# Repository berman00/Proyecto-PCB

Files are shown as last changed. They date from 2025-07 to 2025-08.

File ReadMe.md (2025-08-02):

*english version below*

# Proyecto de Diseño Avanzado de circuitos impresos

por Valentin Berman

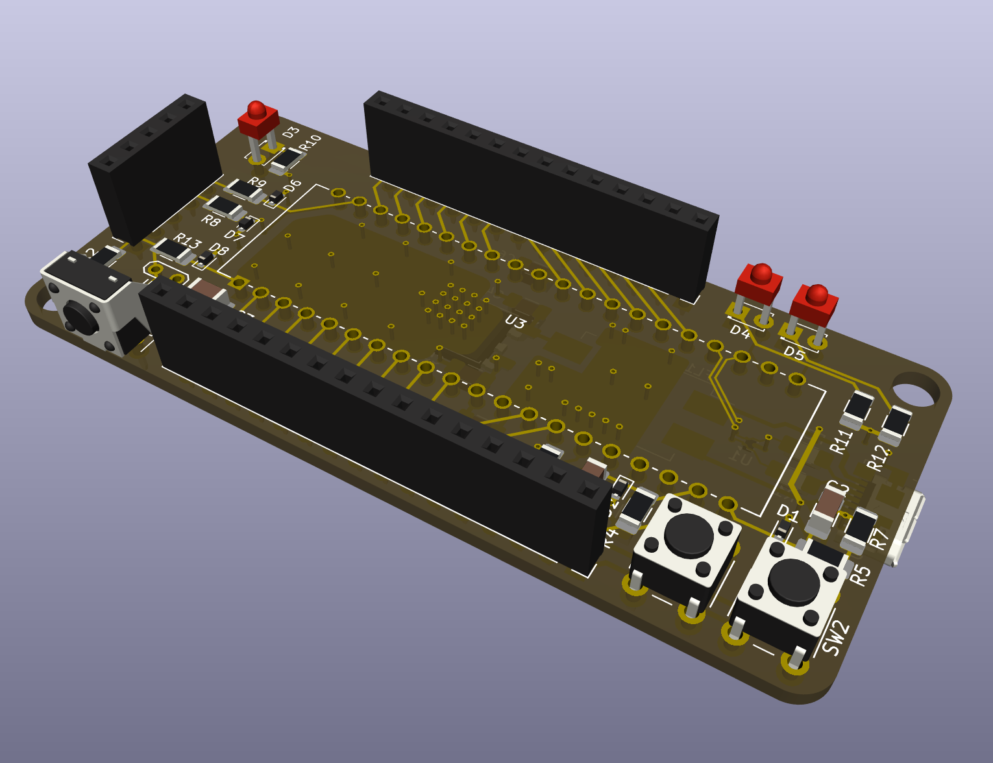
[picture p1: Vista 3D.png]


## Descripción

PCB para un microcontrolador [PIC18 45K50 de Microchip](https://www.microchip.com/en-us/product/PIC18F45K50) con una interfaz humano-máquina simple, pines de GPIO y conector USB.

Diseñado con [KiCad](https://www.kicad.org/).

## Objetivos de diseño

- Usar **partición vertical** para aumentar la compatibilidad electromagnética interna y hacer una placa más compacta. En otras palabras separar los componentes ruidosos de los componentes susceptibles colocándolos en caras opuestas del PCB.

- Elegir componentes que se puedan **soldar a mano** en la medida de lo posible.

- Diseñar **protección contra ESD** en lugares susceptibles.

- Tomar precauciones para **reducir el ruido de alimentación**.

## Guía para usar

Si tenés git instalado podes clonar el repositorio con el comando:

```shell
git clone https://github.com/berman00/Proyecto-PCB.git
```

Sino, podes descargar todos los archivos como un .zip haciendo click en el botón "Code" y luego "Descargar zip".

La repo esta organizada de la siguiente manera:

- **Datasheets:** hojas de datos referenciadas en el proyecto.

- **Entregables:** archivos entregados para evaluar el proyecto.

- **Esquemáticos de referencia:** Esquemáticos de proyectos similares.

- **Proyecto-diseño-PCB:** Proyecto de KiCad.

- **ul_PIC18LF45K50-I-P:** Modelo del micro PIC18 descargado de Microchip.

Si solo querés descargar el esquemático, o el proyecto de KiCad, los podes encontrar en los [releases](https://github.com/berman00/Proyecto-PCB/releases).

# Advanced PCB Design Project

by Valentin Berman



## Description

PCB for a [PIC18 45K50 Microcontroller by Microchip](https://www.microchip.com/en-us/product/PIC18F45K50) with a simple human-machine interface, GPIO pins, and USB connector.

Designed with [KiCad](https://www.kicad.org/).

## Design Goals

- Use **vertical partitioning** to improve internal electromagnetic compatibility and make a more compact board. In other words, separate noisy components from sensitive ones by placing them on opposite sides of the PCB.

- Choose components that can be **hand soldered** as much as possible.

- Design **ESD protection** in susceptible areas.

- Take precautions to **reduce power supply noise**.

## Usage Guide

If you have Git installed, you can clone the repository with the command:

```shell
git clone https://github.com/berman00/Proyecto-PCB.git
```

Otherwise, you can download all the files as a .zip by clicking the "Code" button and then "Download zip".

The repo is organized as follows:

- Datasheets: Data sheets referenced in the project.

- Entregables: Files submitted for project evaluation.

- Esquemáticos de referencia: Schematics from similar projects.

- Proyecto-diseño-PCB: KiCad project.

- ul_PIC18LF45K50-I-P: PIC18 microcontroller model downloaded from Microchip.

If you just want to download the schematic or the KiCad project, you can find them in the [releases](https://github.com/berman00/Proyecto-PCB/releases).

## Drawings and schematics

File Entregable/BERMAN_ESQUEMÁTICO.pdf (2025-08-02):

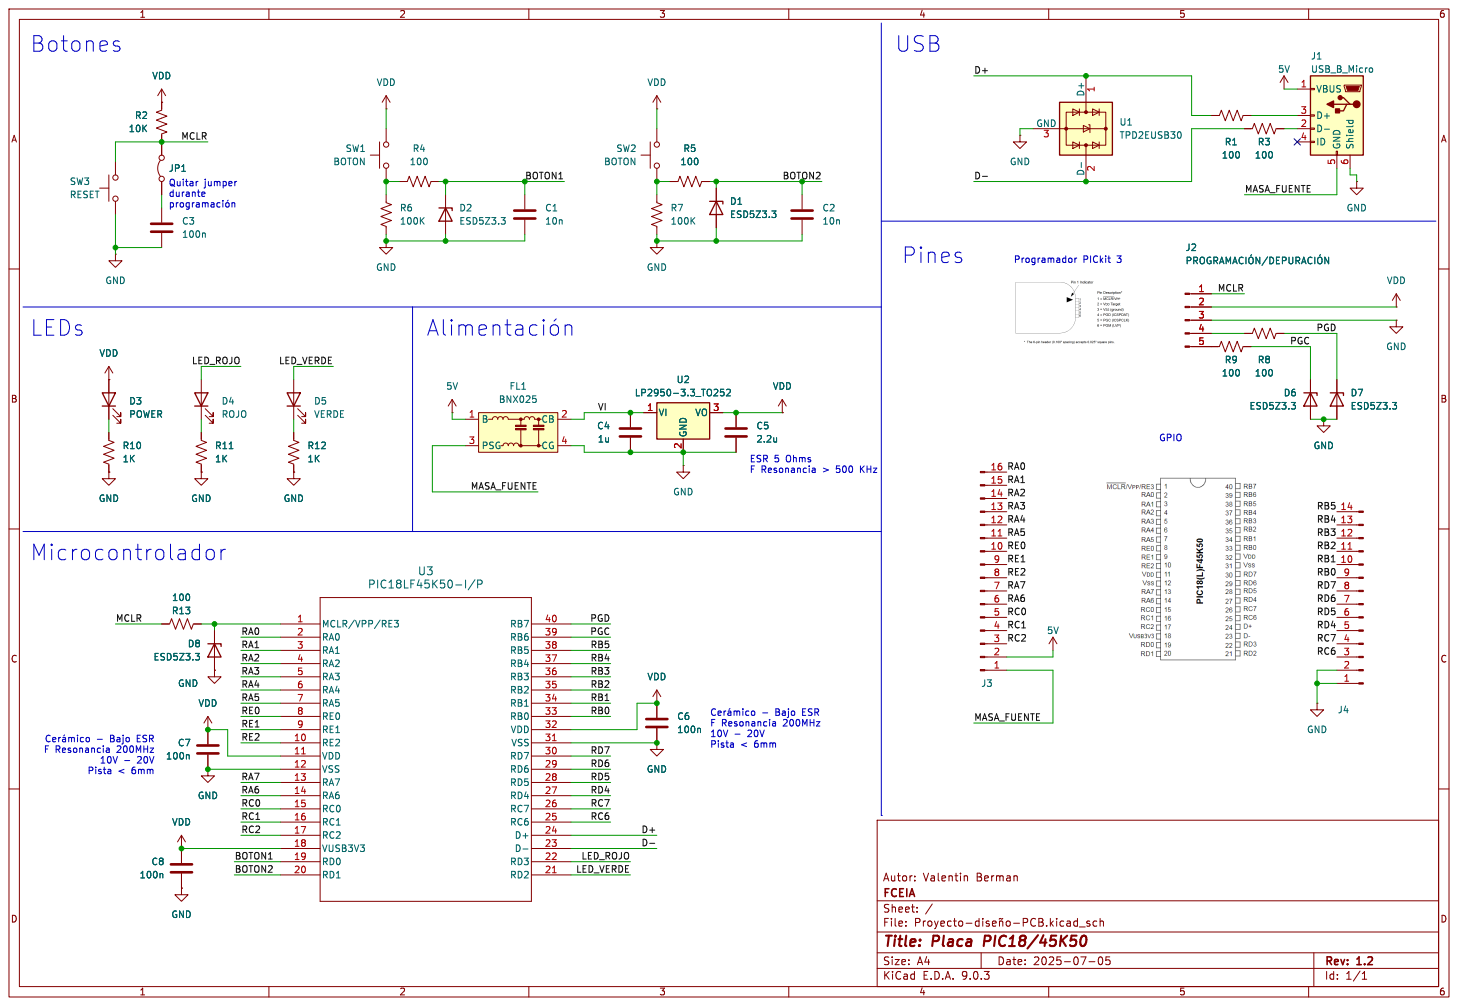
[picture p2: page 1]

File: þÿProyecto-diseño-PCB.kicad_sch Sheet: / FCEIA

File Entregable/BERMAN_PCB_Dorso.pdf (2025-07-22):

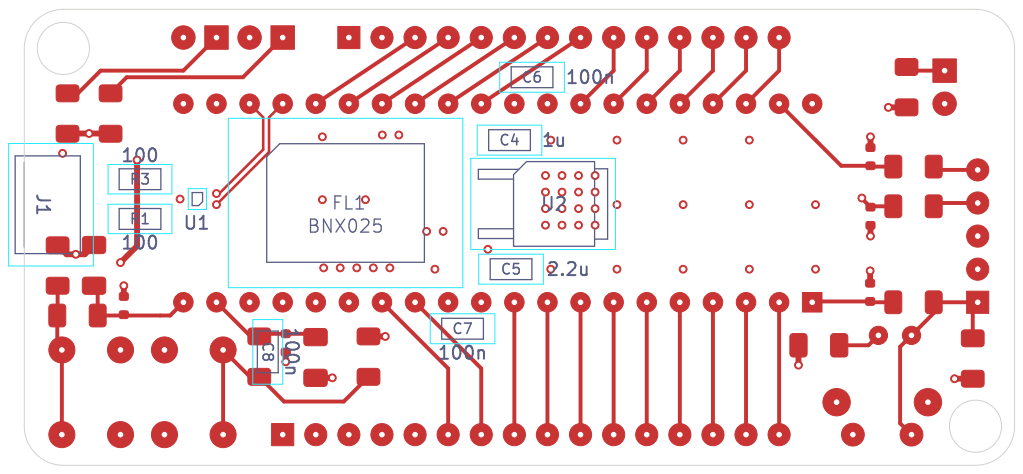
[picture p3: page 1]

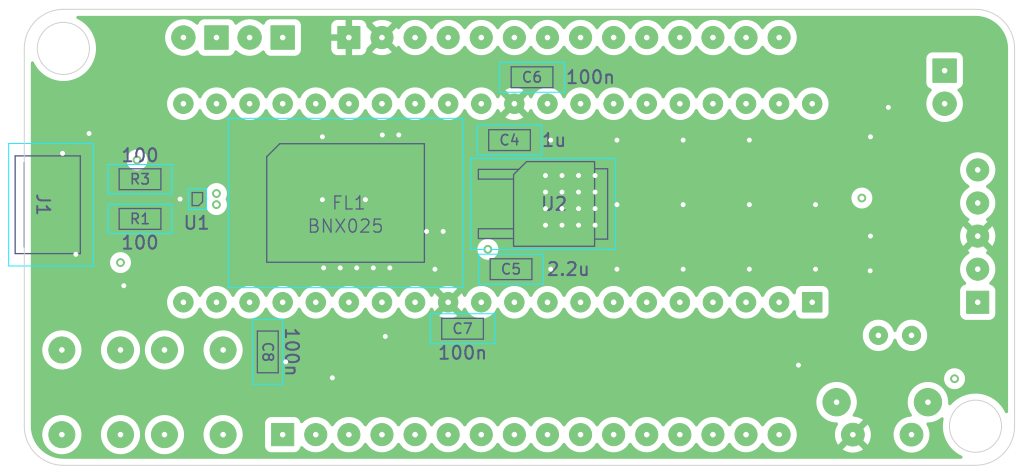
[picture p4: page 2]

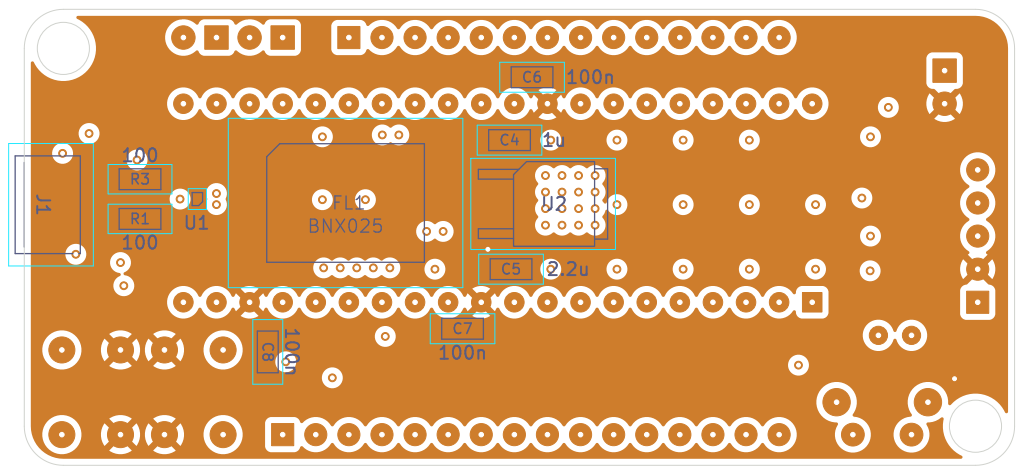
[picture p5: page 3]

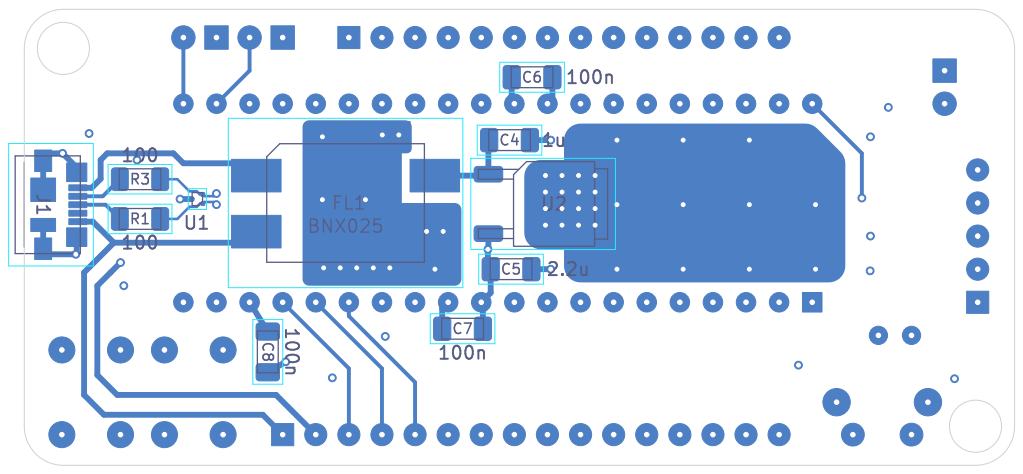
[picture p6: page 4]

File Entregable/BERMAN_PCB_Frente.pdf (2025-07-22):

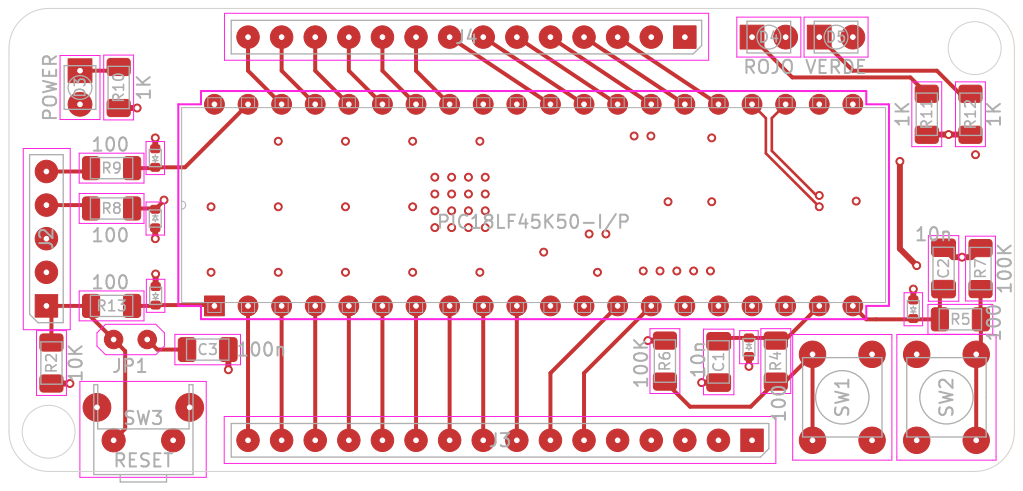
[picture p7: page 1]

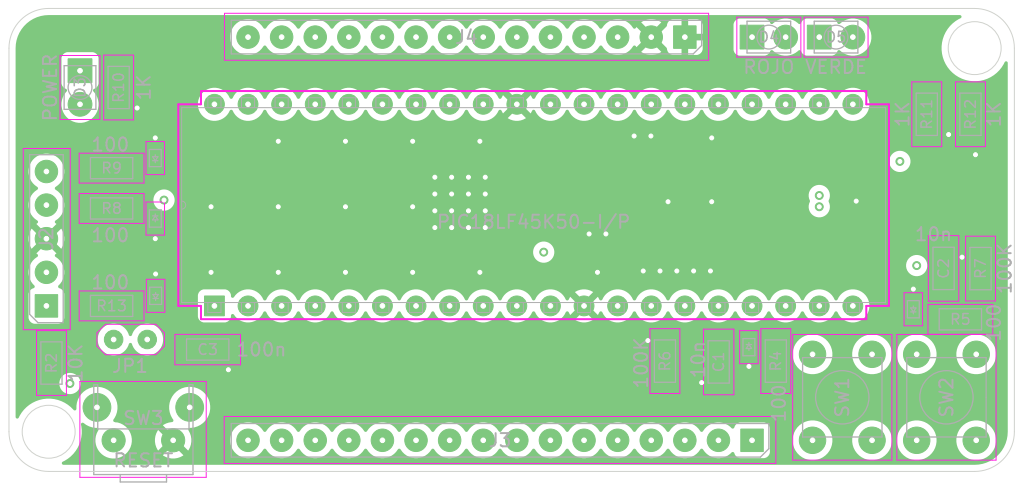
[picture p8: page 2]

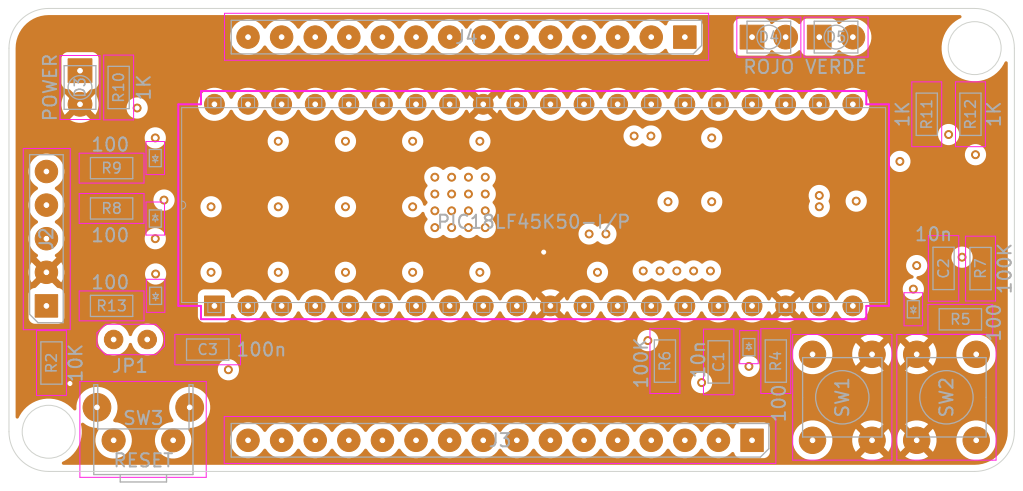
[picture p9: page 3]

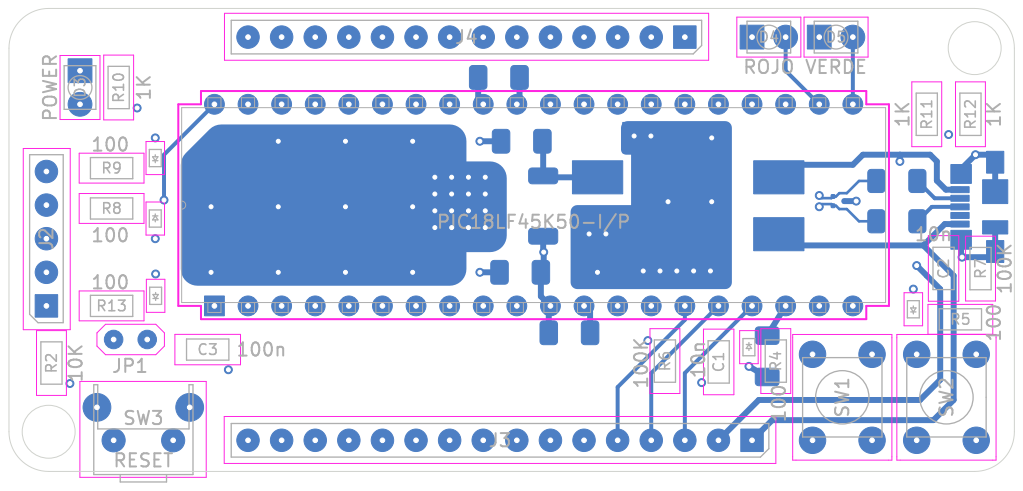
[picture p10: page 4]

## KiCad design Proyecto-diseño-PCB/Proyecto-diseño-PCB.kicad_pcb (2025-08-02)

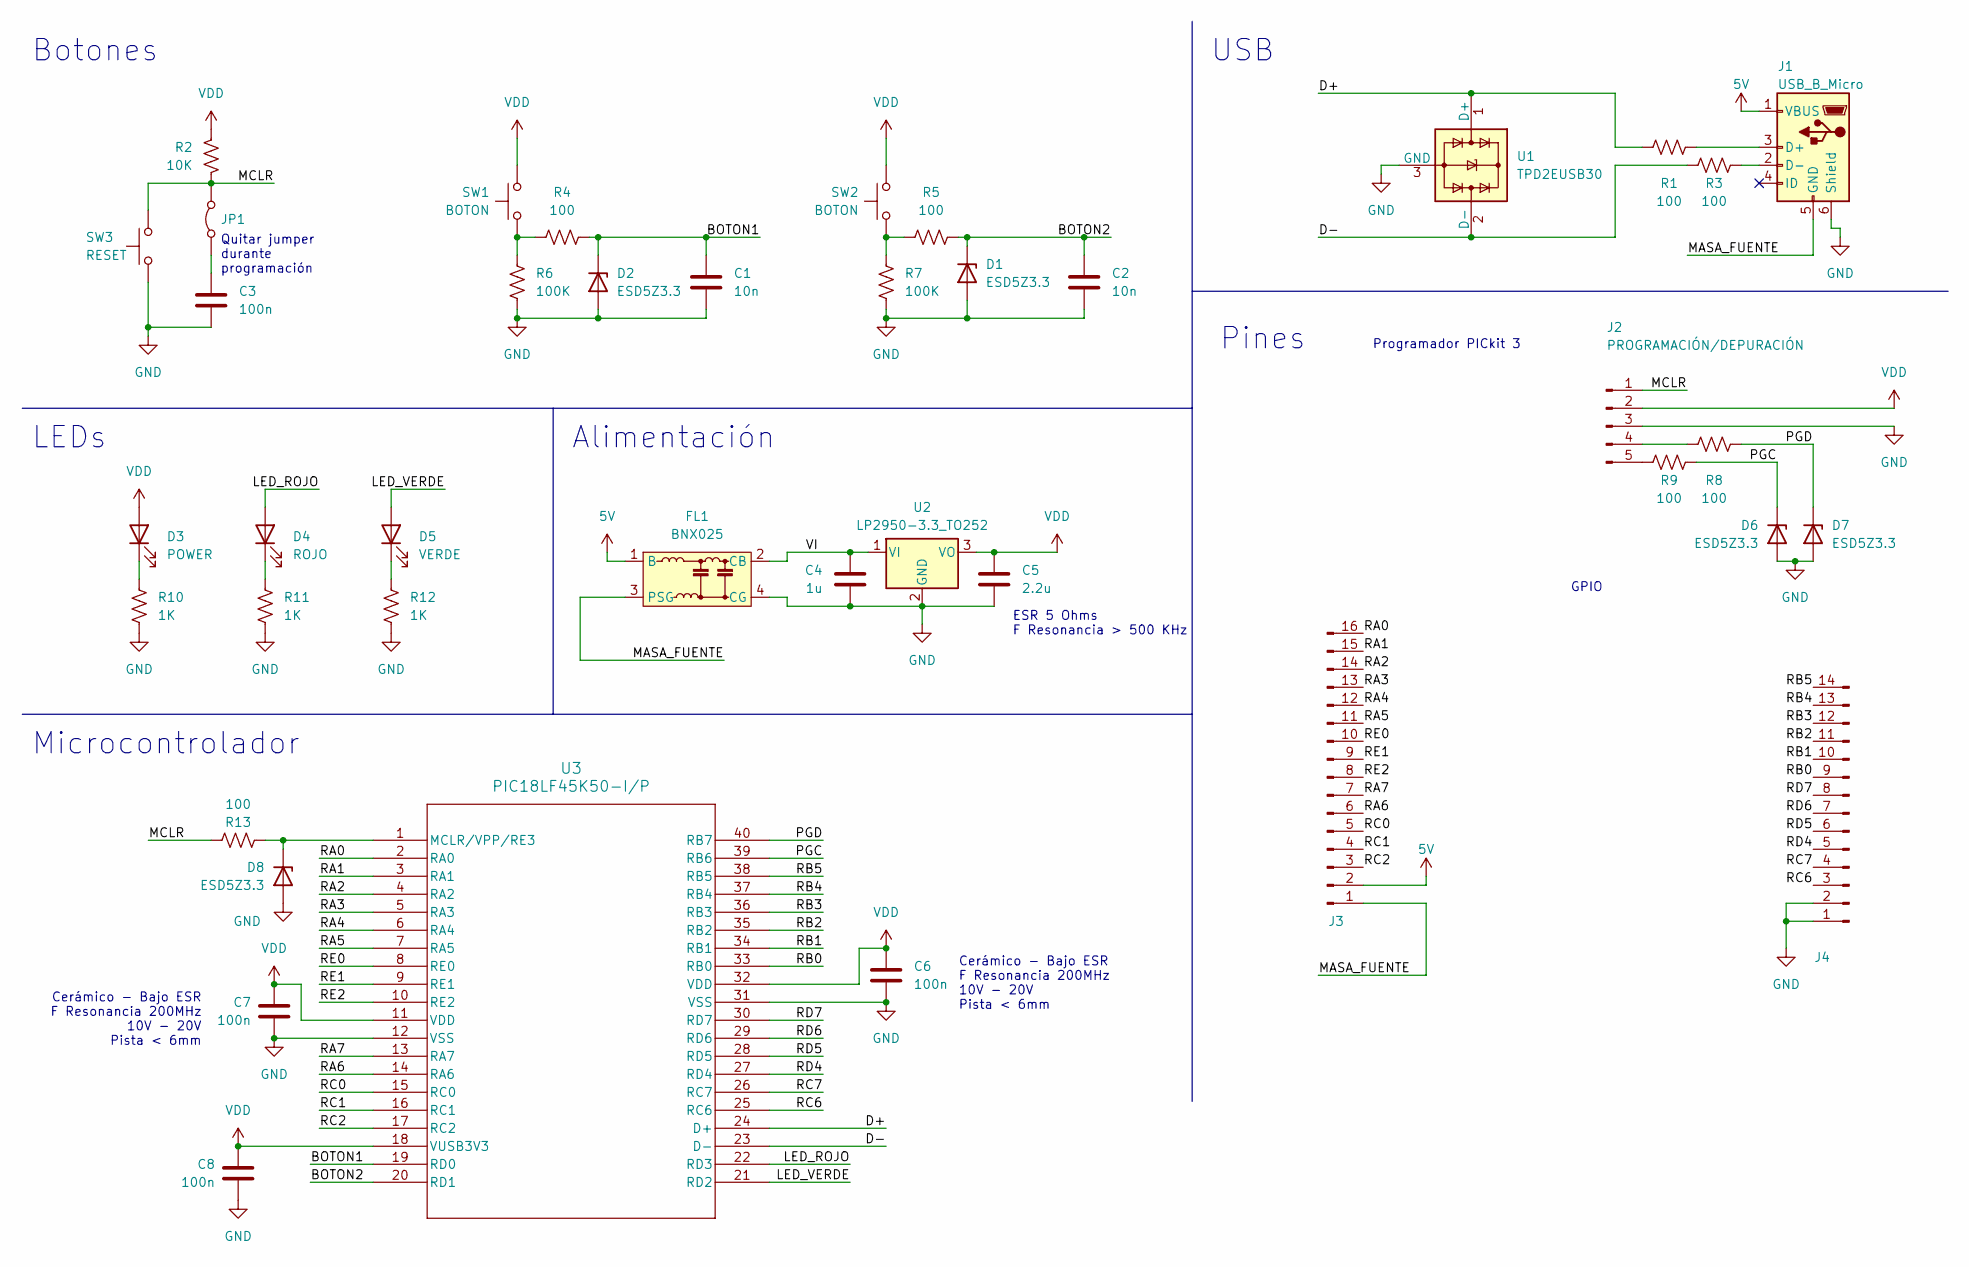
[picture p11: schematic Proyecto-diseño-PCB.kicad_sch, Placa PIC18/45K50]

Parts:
C1, C2: 10n; C_1206_3216Metric_Pad1.33x1.80mm_HandSolder
C3, C6, C7, C8: 100n; C_1206_3216Metric_Pad1.33x1.80mm_HandSolder
C4: 1u; C_1206_3216Metric_Pad1.33x1.80mm_HandSolder
C5: 2.2u; C_1206_3216Metric_Pad1.33x1.80mm_HandSolder
D1, D2, D6, D7, D8: ESD5Z3.3; D_SOD-523
D3: POWER; LED_D1.8mm_W3.3mm_H2.4mm
D4: ROJO; LED_D1.8mm_W3.3mm_H2.4mm
D5: VERDE; LED_D1.8mm_W3.3mm_H2.4mm
FL1: BNX025; Filter_Murata_BNX025
J1: USB_B_Micro; USB_Micro-B_Molex_47346-0001
J2: PROGRAMACIÓN/DEPURACIÓN; PinSocket_1x05_P2.54mm_Vertical
J3: LADO A; PinSocket_1x16_P2.54mm_Vertical
J4: LADO B; PinSocket_1x14_P2.54mm_Vertical
JP1: Jumper_2_Bridged; TestPoint_2Pads_Pitch2.54mm_Drill0.8mm
R1, R3, R4, R5, R8, R9, R13: 100; R_1206_3216Metric_Pad1.30x1.75mm_HandSolder
R2: 10K; R_1206_3216Metric_Pad1.30x1.75mm_HandSolder
R6, R7: 100K; R_1206_3216Metric_Pad1.30x1.75mm_HandSolder
R10, R11, R12: 1K; R_1206_3216Metric_Pad1.30x1.75mm_HandSolder
SW1: BOTON; SW_PUSH_6mm_H4.3mm
SW2: BOTON; SW_PUSH_6mm
SW3: RESET; SW_Tactile_SPST_Angled_PTS645Vx31-2LFS
U1: TPD2EUSB30; Texas_DRT-3
U2: LP2950-3.3_TO252; TO-252-2
U3: PIC18LF45K50-I/P; PDIP40_600MC_MCH

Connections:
5V: FL1.1 (B), J1.1 (VBUS), J3.2
/BOTON1: C1.1, D2.1 (K), R4.2, U3.19 (RD0)
/BOTON2: C2.1, D1.1 (K), R5.2, U3.20 (RD1)
/D+: R1.1, U1.1 (D+), U3.24 (D+)
/D-: R3.1, U1.2 (D-), U3.23 (D-)
/LED_ROJO: D4.2 (A), U3.22 (RD3)
/LED_VERDE: D5.2 (A), U3.21 (RD2)
/MASA_FUENTE: FL1.3 (PSG), J1.5 (GND), J3.1
/MCLR: J2.1, JP1.2 (B), R2.2, R13.2, SW3.2
/PGC: D6.1 (K), R9.2, U3.39 (RB6)
/PGD: D7.1 (K), R8.2, U3.40 (RB7)
/RA0: J3.16, U3.2 (RA0)
/RA1: J3.15, U3.3 (RA1)
/RA2: J3.14, U3.4 (RA2)
/RA3: J3.13, U3.5 (RA3)
/RA4: J3.12, U3.6 (RA4)
/RA5: J3.11, U3.7 (RA5)
/RA6: J3.6, U3.14 (RA6)
/RA7: J3.7, U3.13 (RA7)
/RB0: J4.9, U3.33 (RB0)
/RB1: J4.10, U3.34 (RB1)
/RB2: J4.11, U3.35 (RB2)
/RB3: J4.12, U3.36 (RB3)
/RB4: J4.13, U3.37 (RB4)
/RB5: J4.14, U3.38 (RB5)
/RC0: J3.5, U3.15 (RC0)
/RC1: J3.4, U3.16 (RC1)
/RC2: J3.3, U3.17 (RC2)
/RC6: J4.3, U3.25 (RC6)
/RC7: J4.4, U3.26 (RC7)
/RD4: J4.5, U3.27 (RD4)
/RD5: J4.6, U3.28 (RD5)
/RD6: J4.7, U3.29 (RD6)
/RD7: J4.8, U3.30 (RD7)
/RE0: J3.10, U3.8 (RE0)
/RE1: J3.9, U3.9 (RE1)
/RE2: J3.8, U3.10 (RE2)
/VI: C4.2, FL1.2 (CB), U2.1 (VI)
GND: C1.2, C2.2, C3.2, C4.1, C5.2, C6.2, C7.1, C8.1, D1.2 (A), D2.2 (A), D6.2 (A), D7.2 (A), D8.2 (A), FL1.4 (CG), J1.6 (Shield), J2.3, J4.1, J4.2, R6.2, R7.2, R10.2, R11.2, R12.2, SW3.1, U1.3 (GND), U2.2 (GND), U3.12 (VSS), U3.31 (VSS)
unnamed: D3.1 (K), R10.1
unnamed: D4.1 (K), R11.1
unnamed: D5.1 (K), R12.1
unnamed: D8.1 (K), R13.1, U3.1 (MCLR/VPP/RE3)
unnamed: J1.3 (D+), R1.2
unnamed: J1.2 (D-), R3.2
unnamed: J2.4, R8.1
unnamed: J2.5, R9.1
unnamed: C3.1, JP1.1 (A)
unnamed: R4.1, R6.1, SW1.1
unnamed: R5.1, R7.1, SW2.1
VDD: C5.1, C6.1, C7.2, C8.2, D3.2 (A), J2.2, R2.1, SW1.2, SW2.2, U2.3 (VO), U3.11 (VDD), U3.18 (VUSB3V3), U3.32 (VDD)

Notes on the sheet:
Cerámico - Bajo ESR F Resonancia 200MHz 10V - 20V Pista < 6mm
LEDs
GPIO
Botones
Microcontrolador
USB
Pines
Programador PICkit 3
Quitar jumper durante programación
ESR 5 Ohms F Resonancia > 500 KHz
Alimentación

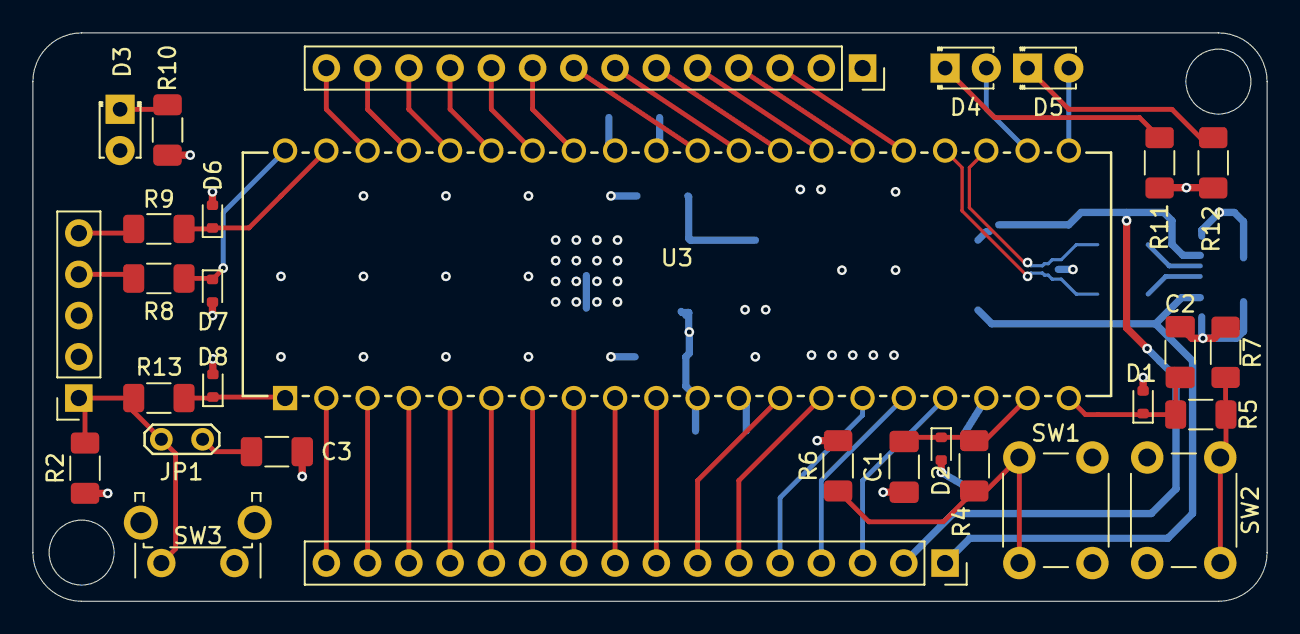
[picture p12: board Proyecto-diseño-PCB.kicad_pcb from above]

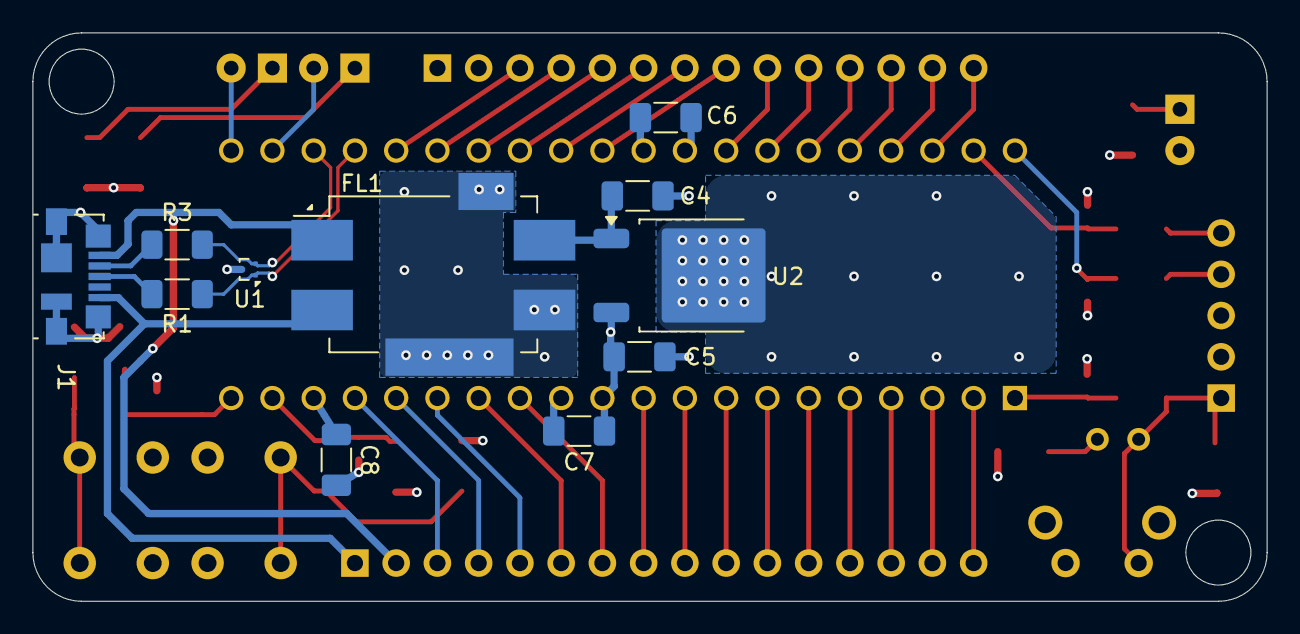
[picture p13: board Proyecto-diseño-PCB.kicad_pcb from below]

Board: 4 copper layers, 76.0 x 35.0 mm, 41 parts (11 on the bottom side), 51 nets.

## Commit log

2025-07-08 Commit inicial
    [Proyecto-diseño-PCB.kicad_pcb, Proyecto-diseño-PCB.kicad_sch]
2025-07-11 fix: Cambio de nombre de net label
    [Proyecto-diseño-PCB.kicad_sch]
2025-07-13 fix: protección ESD
    [Proyecto-diseño-PCB.kicad_sch]
2025-07-15 capacitores de filtro en pines de botones de entrada
    [Proyecto-diseño-PCB.kicad_sch]
2025-07-15 Asignación de footprints
    [Proyecto-diseño-PCB.kicad_sch]
2025-07-15 Net classes
    [Proyecto-diseño-PCB.kicad_sch]
2025-07-15 Di vuelta pines para que el 1 (cuadrado) sea tierra
    [Proyecto-diseño-PCB.kicad_sch]
2025-07-15 Cambié algunos footprints y componentes
    [Proyecto-diseño-PCB.kicad_sch]
2025-07-15 Inicio PCB
    [Proyecto-diseño-PCB.kicad_pcb]
2025-07-17 rest of the f-ing owl
    [Proyecto-diseño-PCB.kicad_pcb, Proyecto-diseño-PCB.kicad_sch]
2025-07-18 estaba haciendo pruebas de las herramientas de kicad
    [Proyecto-diseño-PCB.kicad_pcb]
2025-07-22 Entrega PCB 1
    [Proyecto-diseño-PCB.kicad_pcb]
2025-07-22 Modifiqué tamaño de pistas
    [Proyecto-diseño-PCB.kicad_pcb]
2025-07-22 Correccion: vias separadas de pads
    [Proyecto-diseño-PCB.kicad_pcb]
2025-07-22 Correccion: agregue isla para disipacion de calor
    [Proyecto-diseño-PCB.kicad_pcb]
2025-07-22 Entrega PCB 2
    new file: Entregable/BERMAN_PCB_Dorso_v2.pdf
    new file: Entregable/BERMAN_PCB_Frente_v2.pdf
    renamed: Esquemático/BERMAN_Placa_45K50.pdf -> Entregable/BERMAN_Placa_45K50.pdf
    renamed: Esquemático/BERMAN_Placa_45K50_v2.pdf -> Entregable/BERMAN_Placa_45K50_v2.pdf
    deleted: Esquemático/BERMAN_PCB_Dorso.pdf
    deleted: Esquemático/BERMAN_PCB_Frente.pdf
    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
    [Proyecto-diseño-PCB.kicad_pcb]
2025-08-02 Preparado para publicar
    [Proyecto-diseño-PCB.kicad_pcb, Proyecto-diseño-PCB.kicad_sch]
